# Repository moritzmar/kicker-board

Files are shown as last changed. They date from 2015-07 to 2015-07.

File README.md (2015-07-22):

# Kicker-Board

This is an university project by the students
- P. Hanneken
- J. Huptas
- K-A. Lehmann
- J. Linssen
- M. Martinius
- J. Niehr
- F. Schneider

It demonstrates the use of the RFM24W RF module
for simple communications between a master node and a slave node.

## Hardware

For schematics and board files refer to the schematics folder.

## Software

The software is written in arduino-c and should work on standard Arduinos.
Please note the custom Board config for the arduino-IDE.
It makes heavy use of the RadioHead arduino library, refer to their
documentation regarding RF communications.

## License

This program is free software: you can redistribute it and/or modify
it under the terms of the GNU General Public License as published by
the Free Software Foundation, either version 3 of the License, or
(at your option) any later version.

This program is distributed in the hope that it will be useful,
but WITHOUT ANY WARRANTY; without even the implied warranty of
MERCHANTABILITY or FITNESS FOR A PARTICULAR PURPOSE.  See the
GNU General Public License for more details.

You should have received a copy of the GNU General Public License
along with this program.  If not, see <http://www.gnu.org/licenses/>.

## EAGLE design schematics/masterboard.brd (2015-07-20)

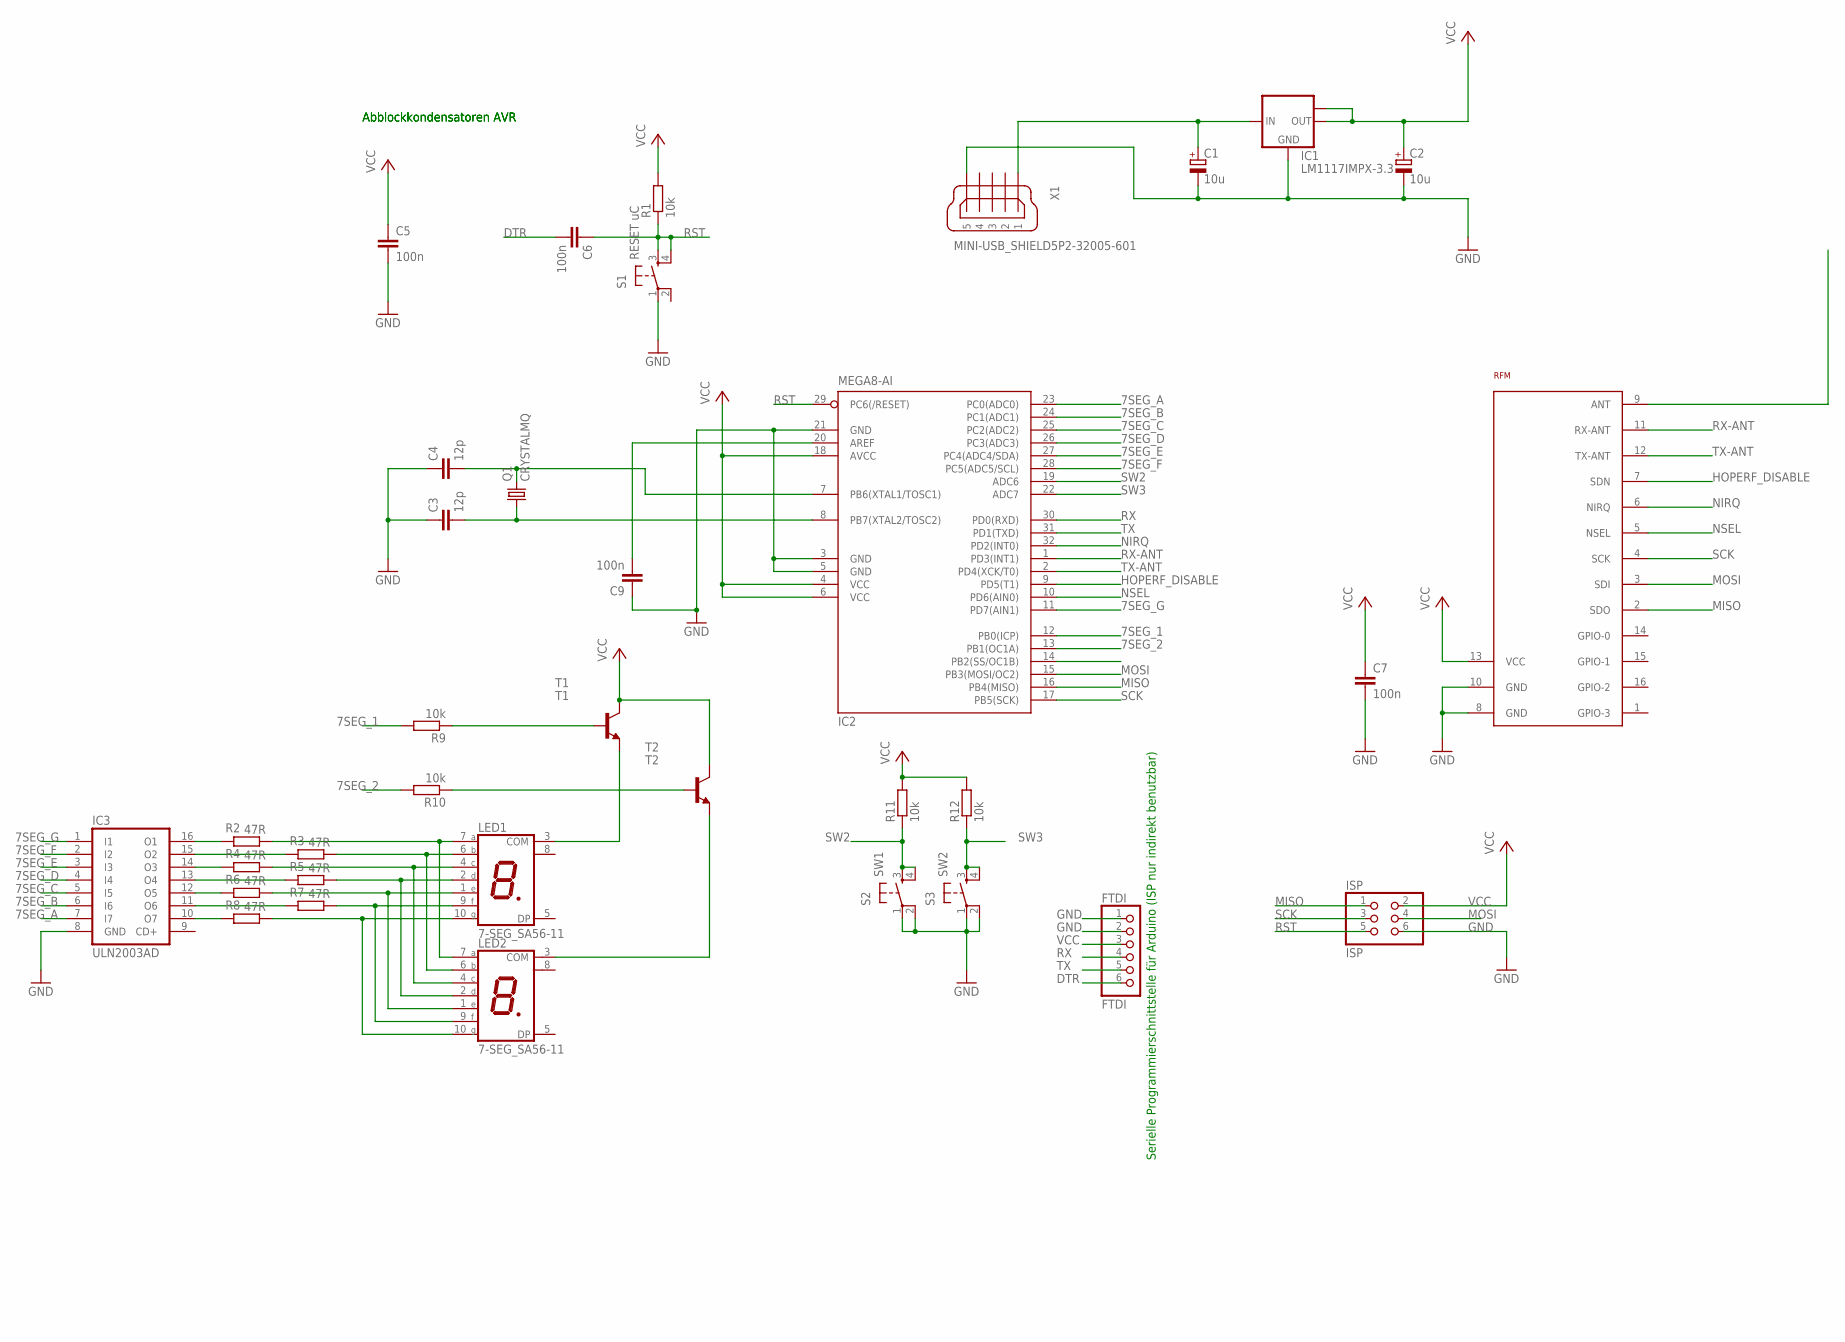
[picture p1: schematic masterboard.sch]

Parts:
C1, C2: 10u; CT6032
C3, C4: 12p; C0603
C5, C6, C7, C9: 100n; C0603
FTDI: FTDI; 1X06/90
IC1: LM1117IMPX-3.3; SOT223
IC2: MEGA8-AI; TQFP32-08
IC3: ULN2003AD; SO16
ISP: ISP; 2X03
LED1, LED2: 7-SEG_SA56-11; SA56-11
Q1: CRYSTALMQ; MQ
R1, R9, R10, R11, R12: 10k; R0805
R2, R3, R4, R5, R6, R7, R8: 47R; R0805
RFM: HOPERF-DB
S1: RESET uC; RAFI
S2: SW1; RAFI
S3: SW2; RAFI
T1: T1; SOT89-BCE
T2: T2; SOT89-BCE
X1: MINI-USB_SHIELD5P2-32005-601; 32005-601

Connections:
7SEG_1: IC2.12 (PB0(ICP)), R9.2
7SEG_2: IC2.13 (PB1(OC1A)), R10.2
7SEG_A: IC2.23 (PC0(ADC0)), IC3.7 (I7)
7SEG_B: IC2.24 (PC1(ADC1)), IC3.6 (I6)
7SEG_C: IC2.25 (PC2(ADC2)), IC3.5 (I5)
7SEG_D: IC2.26 (PC3(ADC3)), IC3.4 (I4)
7SEG_E: IC2.27 (PC4(ADC4/SDA)), IC3.3 (I3)
7SEG_F: IC2.28 (PC5(ADC5/SCL)), IC3.2 (I2)
7SEG_G: IC2.11 (PD7(AIN1)), IC3.1 (I1)
DTR: C6.2, FTDI.6
GND: C1.-, C2.-, C3.1, C4.1, C5.2, C7.2, C9.1, FTDI.1, FTDI.2, IC1.1 (GND), IC2.3 (GND), IC2.5 (GND), IC2.21 (GND), IC3.8 (GND), ISP.6, RFM.8 (GND), RFM.10 (GND), S1.1, S2.1, S2.2 (P1), S3.1, S3.2 (P1), X1.5
HOPERF_DISABLE: IC2.9 (PD5(T1)), RFM.7 (SDN)
MISO: IC2.16 (PB4(MISO)), ISP.1, RFM.2 (SDO)
MOSI: IC2.15 (PB3(MOSI/OC2)), ISP.4, RFM.3 (SDI)
unnamed: C3.2, IC2.8 (PB7(XTAL2/TOSC2)), Q1.P1 (1)
unnamed: C4.2, IC2.7 (PB6(XTAL1/TOSC1)), Q1.P3 (2)
unnamed: C1.+, IC1.3 (IN), X1.1
unnamed: C9.2, IC2.20 (AREF)
unnamed: IC3.16 (O1), R2.2
unnamed: LED1.7 (A), LED2.7 (A), R2.1
unnamed: IC3.15 (O2), R3.2
unnamed: LED1.6 (B), LED2.6 (B), R3.1
unnamed: IC3.14 (O3), R4.2
unnamed: LED1.4 (C), LED2.4 (C), R4.1
unnamed: IC3.13 (O4), R5.2
unnamed: LED1.2 (D), LED2.2 (D), R5.1
unnamed: IC3.12 (O5), R6.2
unnamed: LED1.1 (E), LED2.1 (E), R6.1
unnamed: IC3.11 (O6), R7.2
unnamed: LED1.9 (F), LED2.9 (F), R7.1
unnamed: IC3.10 (O7), R8.2
unnamed: LED1.10 (G), LED2.10 (G), R8.1
unnamed: LED1.3 (COM), T1.E
unnamed: LED2.3 (COM), T2.E
unnamed: R10.1, T2.B
unnamed: R9.1, T1.B
NIRQ: IC2.32 (PD2(INT0)), RFM.6 (NIRQ)
NSEL: IC2.10 (PD6(AIN0)), RFM.5 (NSEL)
RST: C6.1, IC2.29 (PC6(/RESET)), ISP.5, R1.1, S1.3 (S), S1.4 (S1)
RX: FTDI.4, IC2.30 (PD0(RXD))
RX-ANT: IC2.1 (PD3(INT1)), RFM.11 (RX-ANT)
SCK: IC2.17 (PB5(SCK)), ISP.3, RFM.4 (SCK)
SW2: IC2.19 (ADC6), R11.1, S2.3 (S), S2.4 (S1)
SW3: IC2.22 (ADC7), R12.1, S3.3 (S), S3.4 (S1)
TX: FTDI.5, IC2.31 (PD1(TXD))
TX-ANT: IC2.2 (PD4(XCK/T0)), RFM.12 (TX-ANT)
VCC: C2.+, C5.1, C7.1, FTDI.3, IC1.2 (OUT), IC1.TAB (OUT1), IC2.4 (VCC), IC2.6 (VCC), IC2.18 (AVCC), ISP.2, R1.2, R11.2, R12.2, RFM.13 (VCC), T1.C, T2.C

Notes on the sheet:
Abblockkondensatoren AVR
Serielle Programmierschnittstelle für Arduino (ISP nur indirekt benutzbar)

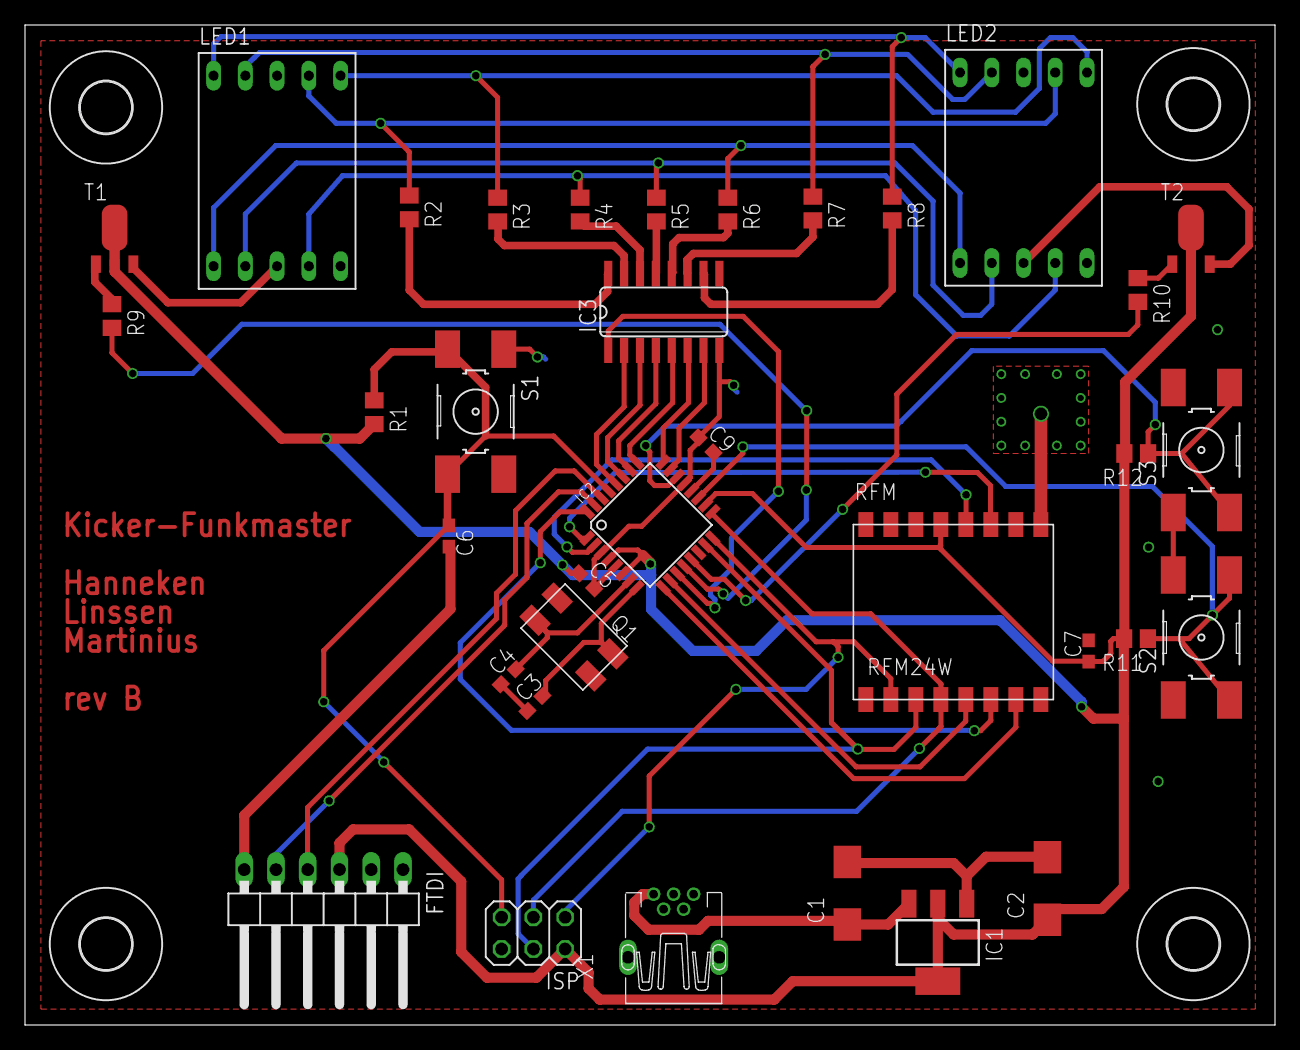
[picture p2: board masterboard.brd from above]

Board: 2 copper layers, 100.0 x 80.0 mm, 39 parts (0 on the bottom side), 47 nets.

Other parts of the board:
U$2, U$3, U$4, U$5: 4,1

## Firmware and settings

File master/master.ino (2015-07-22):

/*
 *  Kicker-Funkmaster
 *  by P. Hanneken; J. Huptas; K-A. Lehmann; J. Linssen; M. Martinius; J. Niehr; F. Schneider
 *
 *
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
 */

#include <SPI.h>
#include <RH_RF24.h>
#include <util/crc16.h>

#define DEBUG 1

#define RFM24_SS 6
#define RFM24_MOSI 11
#define RFM24_MISO 12 
#define RFM24_IRQ 2
#define RFM24_SDN 5


#define DATA_EMPTY 0x00

#define MASTER_SEND_GOAL_RST 0x00
#define MASTER_REQUEST_GOAL 0x01
#define MASTER_REQUEST_BAT_VOLTAGE 0x02
#define MASTER_REQUEST_TEMPERATURE 0x03
#define MASTER_RST 0x0F

#define SLAVE_GOALS_DETECTED 0x11
#define SLAVE_SEND_BAT_VOLTAGE 0x12
#define SLAVE_SEND_TEMPERATURE 0x13
#define SLAVE_OFFSET 0x10



typedef struct node {
  uint8_t address;
  uint8_t order_no;
} node;

node master = {0x01, 0};
node slave_a = {0xBE, 0};
node slave_b = {0xEF, 1};

uint8_t game_end = 0;

static uint8_t score_a = 0;
static uint8_t score_b = 0;

volatile uint16_t btn_a_state = 0;
volatile uint16_t btn_b_state = 0;

volatile uint16_t btn_a_hold = 0;
volatile uint16_t btn_b_hold = 0;

const uint8_t segments_lut_1 [] =  {0x3E, 0x30, 0x2D, 0x39, 0x33, 0x1B, 0x1F, 0x30, 0x3F, 0x3B, 0x0F, 0x00, 0x01}; // 0 1 2 3 4 5 6 7 8 9 E OFF -
const uint8_t segments_lut_2 [] =  {0x80, 0x00, 0x80, 0x80, 0x00, 0x80, 0x80, 0x80, 0x80, 0x80, 0x80, 0x00, 0x00}; // 0 1 2 3 4 5 6 7 8 9 E OFF -


//Initialize a new instance of the RadioHead RFM24W driver as rf24 from the pin defines above
RH_RF24 rf24 = RH_RF24(RFM24_SS, RFM24_IRQ, RFM24_SDN);


/*
 * void timer_setup ()
 * Sets up the Timer2 for multiplexing and debouncing (see ISR(TIMER2_OVF_vect))
 */
void timer_setup(void) {
	TCCR2B |= ((1 << CS22) | (1 << CS21) ); // Prescaler 256 on Timer2
	TIMSK2 |= ((1 << TOIE0)); // Overflow Interrupt enable on Timer 2
	GTCCR &= (~(1 << TSM)); // Start all timers by disabling the synced halt
}


/*
 * void segments_setup()
 * Sets up the 7-segment display module. Note that the pins for the segments are scattered to PORTC and PORTD
 */
void segments_setup(void) {
  	DDRC |= ( (1 << PC0) | (1 << PC1) | (1 << PC2) | (1 << PC3) | (1 << PC4) | (1 << PC5)); // Output pins for 7 segment G-B
	DDRD |= (1 << PD7); // Output pin for 7 segment A

	DDRB |= (1 << PB0) | (1 << PB1); // 7 segment drive transistor
}

/*
 * void segments_worker(uint8_t score_a, uint8_t score_b)
 * arg uint8_t score_a: left score to display
 * arg uint8_t score_b: right score to display
 * note that the values above 9 are special chars, refer to LUT
 *
 * worker function for segment multiplexing, gets periodically called by TIMER2
 */

void segments_worker(uint8_t score_a, uint8_t score_b) {  // Segments multiplexing
	static uint8_t element = 0;
	if(element == 0) {
		PORTB &= ~(1 << PB1); // disable 2nd display element
		element = 1; // set flag for next element
		PORTC &= ~((1 << PC0) | (1 << PC1) | (1 << PC2) | (1 << PC3) | (1 << PC4) | (1 << PC5));
		PORTD &= ~(1 << PD7);
		PORTC |= segments_lut_1[score_a]; // set segment G-B from LUT
		PORTD |= segments_lut_2[score_a]; // set segment A from LUT
		PORTB |= (1 << PB0);  // enable 1st display segment
	}
	else {
		PORTB &= ~(1 << PB0); // disable 1st display element
		element = 0; // set flag for next element
		PORTC &= ~((1 << PC0) | (1 << PC1) | (1 << PC2) | (1 << PC3) | (1 << PC4) | (1 << PC5));
		PORTD &= ~(1 << PD7);
		PORTC |= segments_lut_1[score_b]; // set segment G-B from LUT
		PORTD |= segments_lut_2[score_b]; // set segment A from LUT
		PORTB |= (1 << PB1); // enable 2nd display segment
	}
}

/*
 * void button_worker()
 *
 * worker function for buttons, gets periodically called by TIMER2
 * note that the buttons are connected to analog inputs only, so they can only be read by analogRead()
 */

void button_worker(void) {
  	static uint8_t btn = 0;
	uint16_t btn_current = 0;
  	static uint8_t btn_1_state = 0;
    	static uint8_t btn_2_state = 0;


	if(btn == 0){
		btn_current = analogRead(6);
		if(btn_1_state == 0 && (btn_current < 50)) {
			// button pressed, falling edge
			btn_a_state = 1;
			btn_a_hold = 0;
			btn_1_state = 1;
		}
		else if((btn_1_state == 1 || btn_1_state == 2) && (btn_current < 50)) {
			// button hold
			btn_a_hold++;
			btn_1_state = 2;
		}
		else if(btn_1_state == 2 && (btn_current > 50)) {
			// button released, rising edge
			btn_a_hold = 0;
			btn_1_state = 3;
		}
		else if(btn_1_state == 3 && (btn_current > 50)) {
			// button not pressed
			btn_a_hold = 0;
			btn_1_state = 0;
		}
		btn = 1;
	}
	else {
		btn_current = analogRead(7);
		if(btn_2_state == 0 && (btn_current < 50)) {
			// button pressed, falling edge
			btn_b_state = 1;
			btn_b_hold = 0;
			btn_2_state = 1;
		}
		else if((btn_2_state == 1 || btn_2_state == 2) && (btn_current < 50)) {
			// button hold
			btn_b_hold++;
			btn_2_state = 2;
		}
		else if(btn_2_state == 2 && (btn_current > 50)) {
			// button released, rising edge
			btn_b_hold = 0;
			btn_2_state = 3;
		}
		else if(btn_2_state == 3 && (btn_current > 50)) {
			// button not pressed
			btn_b_hold = 0;
			btn_2_state = 0;
		}
		btn = 0;
	}
}

/*
 * uint8_t calc_crc8(uint8_t * dataIn, uint8_t len)
 * arg uint8_t * dataIn: Points to the data array of the crc8 to generate
 * arg uint8_t len: gives the length of the data to read. Can be zero! Care for out-of-boundary calls!
 * ret uint8_t: returns the calculated CRC8
 *
 * This functions calculates CRC8 sum for the given data with the CCITT polynomial 0x07
 */

uint8_t calc_crc8(uint8_t * dataIn, uint8_t len)
{
  uint8_t i = 0, last_crc = 0;
  for (i = 0; i<len; i++){ // update crc for each byte in data in
    last_crc = _crc8_ccitt_update(last_crc, dataIn[i]);
  }
  return last_crc;
}

/*
 * void PrintHex8(uint8_t *data, uint8_t len)
 * arg uint8_t * data: Points to the data to print
 * arg uint8_t len: gives the length of the data to read. Can be zero! Care for out-of-boundary calls!
 *
 * Used for debugging to print RF packages
 */

void PrintHex8(uint8_t *data, uint8_t len)
{
       Serial.print("0x");
       for (int i=0; i<len; i++) {
         if (data[i]<0x10) {Serial.print("0");}
         Serial.print(data[i],HEX);
         Serial.print(" ");
       }
	Serial.println();
}

/*
 * uint8_t get_goals_from_slave(struct node slave)
 * arg struct node slave: input the slave struct you want to send to
 * ret uint8_t: returns the number of goals the slave buffered (max 9). Returns 0 if slave does not answer. Returns -1 if package is corrupted.
 *
 */

uint8_t get_goals_from_slave(struct node slave) {
 	uint8_t data[4] = {};
  	uint8_t buf[4];
  	uint8_t res = 0;

  	uint8_t len = sizeof(buf);

  	// build package for goal request
  	data[0] = slave.address;
  	data[1] = MASTER_REQUEST_GOAL;
  	data[2] = DATA_EMPTY;
  	data[3] = calc_crc8(data, 3);
	#ifdef DEBUG
	  	Serial.print("Sending Request to slave 0x");
	  	Serial.print(slave.address, HEX);
	  	Serial.println(":");
	  	PrintHex8(data, 4);
	#endif

  	// send goal request
  	rf24.send(data, sizeof(data));
  	rf24.waitPacketSent();

	if (rf24.waitAvailableTimeout(500)) { // wait for package and get in from the transceiver
		if (rf24.recv(buf, &len))
		{
			#ifdef DEBUG
				Serial.print("INFO: got reply: ");
				PrintHex8(buf, 4);
				Serial.println();
			#endif
			// check if valid package is recevived
			if(buf[0] == master.address && buf[1] == (SLAVE_GOALS_DETECTED+(slave.order_no*SLAVE_OFFSET)) && calc_crc8(buf, 4) == 0x00 ) {
				if(buf[2] ==0 ) {
					return 0; // bail out if score is 0
				}
				res = buf[2]; // score is valid, save to res

				// package for resetting the score on the slave board
				data[0] = slave.address;
			  	data[1] = MASTER_SEND_GOAL_RST;
			  	data[2] = DATA_EMPTY;
			  	data[3] = calc_crc8(data, 3);
				#ifdef DEBUG
					Serial.print("INFO: Sending score reset request to slave 0x");
					Serial.print(slave.address, HEX);
	  				Serial.println(":");
				  	PrintHex8(data, 4);
				#endif
				// send score reset request
				rf24.send(data, sizeof(data));
  				rf24.waitPacketSent();
			}
			else {
				Serial.print("ERROR: Package broken or wrong CRC8 from slave 0x");
				Serial.print(slave.address, HEX);
  				Serial.println("!");
				return -1; // hard failure, bail out
			}
		}
		else {
			Serial.println("WARNING: Receiving failed!");
			return 0; // soft failure, just dont update score
		}
	}
	else {
		Serial.print("WARNING: No reply, is Slave 0x");
		Serial.print(slave.address, HEX);
  		Serial.println(" running?");
		return 0; // soft failure, just dont update score
	}

	return res; // return score if everything succeeds

}

void setup() {
        cli(); // global Interrupt disable, prevents flicker while initialzing

	segments_setup();
	timer_setup();

        Serial.begin(115200);
        Serial.println("Kicker-Funkmaster up and running!");
        Serial.println("by P. Hanneken; J. Huptas; K-A. Lehmann; J. Linssen; M. Martinius; J. Niehr; F. Schneider");
  	Serial.println("This program is open source and licensed under the conditions of the GNU GPL v3!");
  	Serial.println("This program is distributed in the hope that it will be useful, but WITHOUT ANY WARRANTY; without even the implied warranty of MERCHANTABILITY or FITNESS FOR A PARTICULAR PURPOSE.  See the GNU General Public License for more details.");

        if (!rf24.init())  { //Initialisierung des Funkmoduls fehlgeschlagen?
            Serial.println("Init failed");
        }
        #ifdef DEBUG
		else {
		  Serial.println("RF24 successfully initialized");
		}
        #endif



        sei(); // global Interrupt enable
}

void loop() {
  	uint8_t slave_res = 0;

	if( btn_a_hold > 46) {
		score_a = 0;
		score_b = 0;
		btn_a_hold = 0;
		game_end = 0;
	}

	if( btn_b_state == 1) {
		btn_a_hold = 0;
	}

	if(game_end == 0) {
		if(btn_a_state == 1 && btn_b_state != 1) {
			score_a++;
			btn_a_state = 0;
		}
		if(btn_b_state == 1 && btn_a_state != 1) {
			score_b++;
			btn_b_state = 0;
		}

		slave_res = get_goals_from_slave(slave_a);

		if(slave_res >= 0 && slave_res<=9 && score_a <= 9) {
			score_a += slave_res;
		}
		else if (slave_res = -1){
			score_b = 10;
		}

		slave_res = get_goals_from_slave(slave_b);

		if(slave_res >= 0 && slave_res<=9 && score_b <= 9) {
			score_b += slave_res;
		}
		else if (slave_res = -1){
			score_b = 10;
		}
	}

	if(score_a >= 10 && game_end == 0) {
		game_end = 1;
		Serial.println("Team A won the game!");
		score_a = 12;
		score_b = 11;
	}
	if(score_b >= 10 && game_end == 0) {
		game_end = 1;
		Serial.println("Team B won the game!");
		score_b = 12;
		score_a = 11;
	}
}

ISR(TIMER2_OVF_vect) { // Will be called with roughly 183,1 Hz
	segments_worker(score_a, score_b);
	button_worker();
}

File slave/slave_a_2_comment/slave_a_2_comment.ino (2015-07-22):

/********************************************************************************************************
 * title: soccer_table_goal_control
 * developers:  Hanneken, Patrick
 *              Huptas, Jill Catherine
 *              Lehmann, Kjell-Arne
 *              Linssen, Janina
 *              Martinius, Moritz
 *              Niehr, Jan Henrik
 *              Schneider, Fabian

********************************************************************************************************/
#include <RH_RF24.h>
// Singleton instance of the radio driver
#include <SPI.h>
#include <TimerOne.h>
#include <util/crc16.h>


#define RFM24_SS 6
#define RFM24_MOSI 11
#define RFM24_MISO 12 
#define RFM24_IRQ 2
#define RFM24_SDN 5
RH_RF24 rf24 = RH_RF24(RFM24_SS, RFM24_IRQ, RFM24_SDN); //Initialize a new instance of the RadioHead RFM24W driver as rf24

//********************************************************************************************************
//program settings Slave A

#define my_address slave_a_address
#define request_zero 0x00
#define request_goal 0x01
#define request_temp 0x02
#define request_batt 0x03
#define request_reset 0x0F

#define response_goal 0x11
#define response_batt 0x12
#define response_temp 0x13


//********************************************************************************************************

volatile uint16_t btn_a_state = 0;
volatile uint16_t btn_a_hold = 0;

unsigned char Master_address = 0x01;  // address for master
unsigned char slave_a_address = 0xBE; // address for slave a 
unsigned char slave_b_address = 0xEF; // address for slave b
uint8_t last_crc;                     // result of crc8 calculation
//uint8_t AddressTemp, Data1Temp, Data2Temp, crc8Temp, Address, Data1, Data2, crc8;   
uint8_t package[4]={};                // array for four byte data package
uint8_t goal = 0;                     // declaration for number of goals
uint8_t batt;                         // initialization of battery variable
uint8_t temp;                         // initialization of temperature variable

uint8_t calc_crc8(uint8_t * package, uint8_t len){               // function for crc8 calculation; uses the ccitt generator polynom 0x07
  uint8_t i = 0, last_crc = 0;        
  for (i = 0; i<len; i++){
    last_crc = _crc8_ccitt_update(last_crc, package[i]);
  }
  return last_crc;
}

void PrintHex8(uint8_t *data, uint8_t length){                   // prints 8-bit data in hex with leading zeroes
       Serial.print("0x"); 
       for (int i=0; i<length; i++) { 
         if (data[i]<0x10) {Serial.print("0");} 
         Serial.print(data[i],HEX); 
         Serial.print(" "); 
       }
        Serial.println();
}
void goal_worker(void){                                         // button request for goal counter
    static uint8_t goal_state = 0;
        uint16_t goal_current = 0;

    goal_current = digitalRead(A1);
    if(goal_state == 0 && (goal_current == LOW)) {
      // taster gedrueckt, fallende flanke
      goal_state = 1;
                goal++;
      }
    else if((goal_state == 1) && (goal_current == LOW)) {
                // gehalten
      goal_state = 2;
    }
    else if(goal_state == 2 && (goal_current == HIGH)) {
      // taster wird los gelassen
      goal_state = 3;
    }
    else if(goal_state == 3 && (goal_current == HIGH)) {
      // taster nicht gedrueckt
      goal_state = 0;
    }
}

void timer_setup(void) {
  TCCR2B |= ((1 << CS22) | (1 << CS21) );                       // prescaler 256 on Timer2
  TIMSK2 |= ((1 << TOIE0));                                     // overflow Interrupt enable on Timer 2
  GTCCR &= (~(1 << TSM));                                       // start all timers by disabling the synced halt
}

uint8_t check_batt(void){
  float voltage;                          // variable for battery voltage
  uint8_t volt_return;                    // variable to convert the battery voltage to one byte
  voltage = rf24.get_battery_voltage();   // request
  voltage += 0.5;                         // round up or down to the next integer
  volt_return = voltage;                  // cast
  return volt_return;                     // return 
}

uint8_t check_temp(void){
  float temperature;                      // variable for temperature
  uint8_t temp_return;                    // voriable to convert the temperature to one byte
  temperature = rf24.get_temperature();   // request
  temperature += 0.5;                     // round up or down to the next integer
  temp_return = temperature;              // cast
  return temp_return;                     // return
}

//********************************************************************************************************
//begin of setup
  
void setup() 
{
  pinMode(A1, INPUT);         // Pinbelegung für den Knopf, später durch die Lichtschranke ersetzen

  timer_setup();              // initialize of timer function
  
  Serial.begin(115200);       // setting serial interface (baudrate)
  if (!rf24.init())           // case of hardware connection fail
    Serial.println("init failed");
}

//********************************************************************************************************
//begin of forever loop
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

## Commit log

2015-07-20 Added EAGLE schematic and board files
    [masterboard.brd, masterboard.sch, slaveboard.brd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]
2015-07-20 Added libs for schematics
2015-07-20 Bitte geben Sie eine Commit-Beschreibung für Ihre Änderungen ein. Zeilen, fixed duplicate files
    [master.ino]
2015-07-22 small fix regarding slave reset request
    [master.ino]
2015-07-22 Slave a und b finale Version Kommentiert
